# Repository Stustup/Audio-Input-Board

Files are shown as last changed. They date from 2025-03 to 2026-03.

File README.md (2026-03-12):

# Audio Input Board

A simple input board to interface multiple connectors with DIY projects. I use it mainly as connector boards for prototyping tube amps, which are wired point to point. Adding flimsy cables with connectors soldered to them was and would be tedious. 
Also this makes it possible to securely attach oscilloscope probes on the test holes.

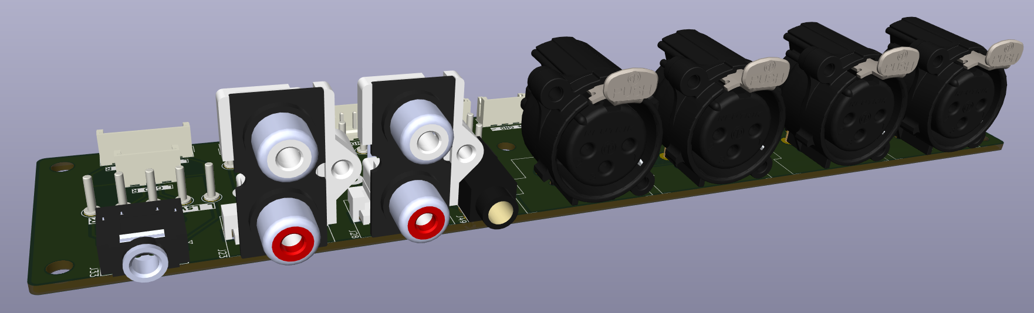
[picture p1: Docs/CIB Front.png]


## Connectors on the board are:
1. 3.5mm Stereo Jack
2. 2 Stereo Chinch/RCA connectors (for input/output)
3. 4.4mm Differential Pentaconn connector, because i like it and want to push it.
3. 4 Mono Differential XLR connectors (for input/output). One could use each of these as a single stereo Jack 

To interface these connectors to your DIY project you need a few JST_EH P2.50mm connectors and cables, which are the (it looks like to me) standard for cheap knock off DIY connectors in sets on eBay. 

You could also just solder wires to the holes corresponding to the input jack.

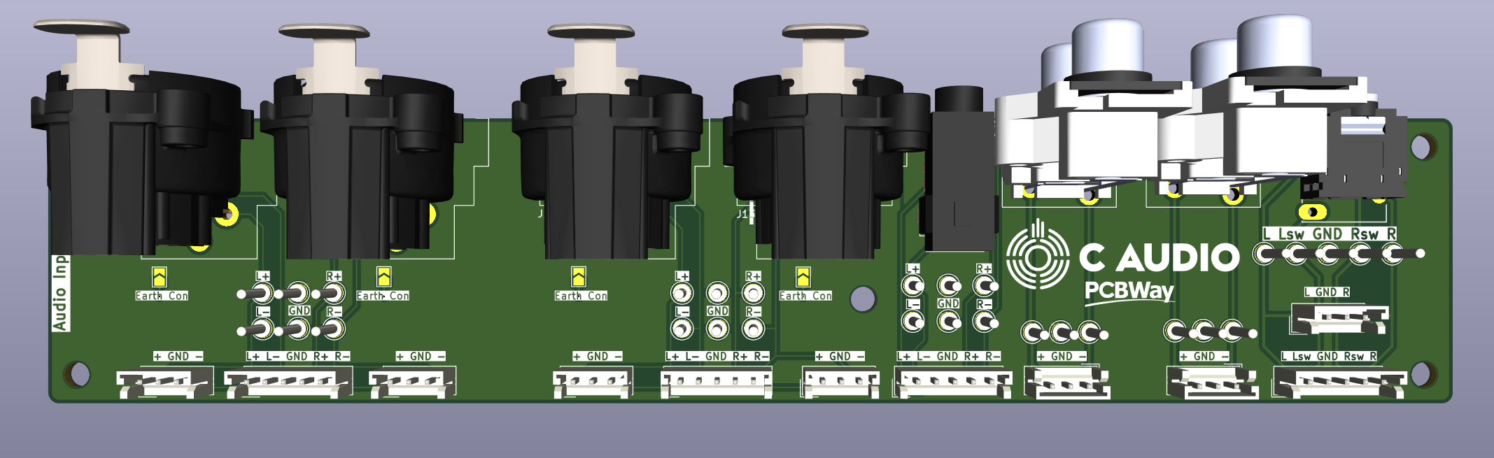
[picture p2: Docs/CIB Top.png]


The XLR connectors wre wired somewhat weirdly, like you can see in the next picture:

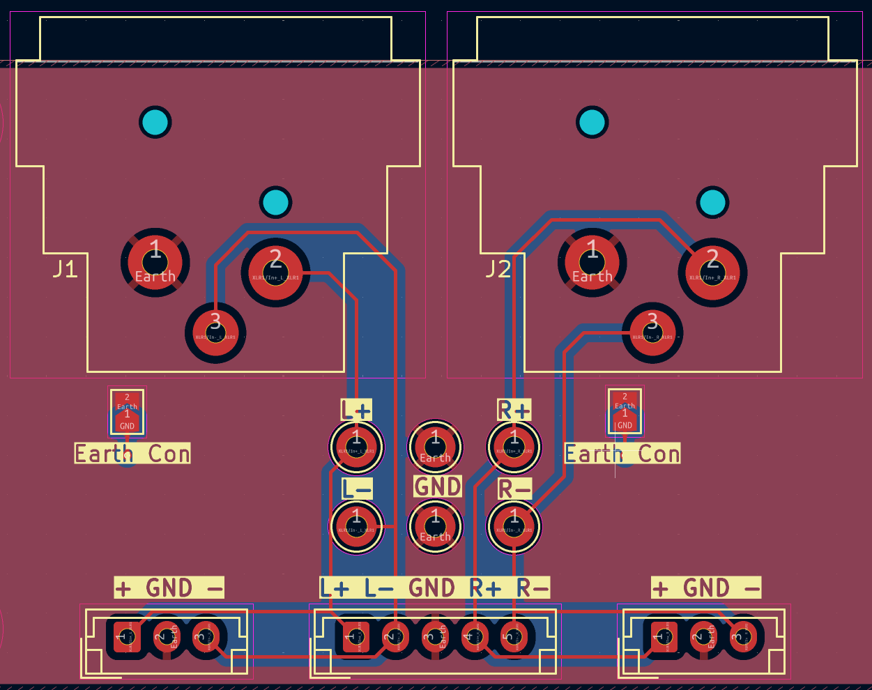
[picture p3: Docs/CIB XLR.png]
XLR connections


As you can see, the top pins are the hot pins and the bottom pins are the cold pins. Use this as you like. The pin 1 of the XLR (used for ground or Earth) is connected only to the GND plane on the XLR side. To connect this to the GND of the single ended Jacks (RCA and 3.5mm) and the pentaconn one you have to solder the little "Earth_Con" jumper. 

The switched contacts of the 3.5mm jack are broken out, too.

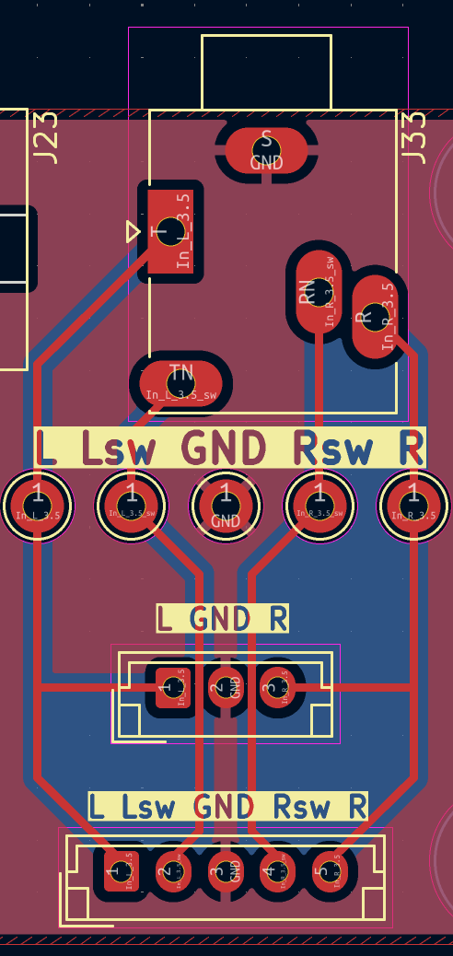
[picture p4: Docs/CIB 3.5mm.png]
Stereo Jack wiring


## Notes

The 3D models of the connectors are not in this repository, you can grab these on GrabCAD.

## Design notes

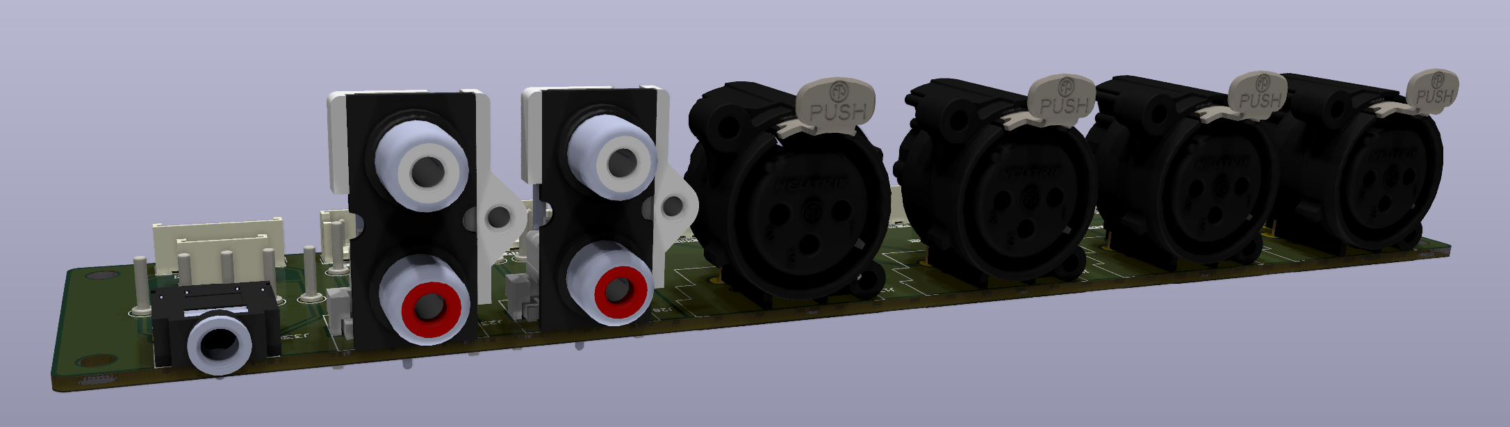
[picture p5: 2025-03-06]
Docs/3d-model-front.png

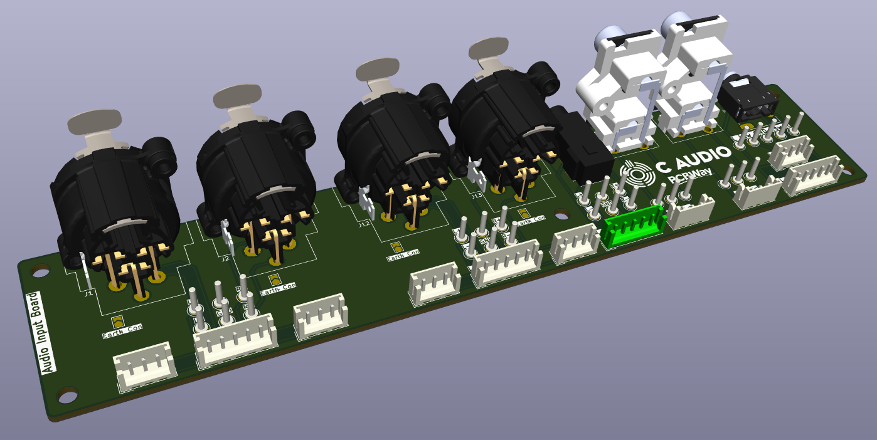
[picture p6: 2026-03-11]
Docs/CIB Back side.png

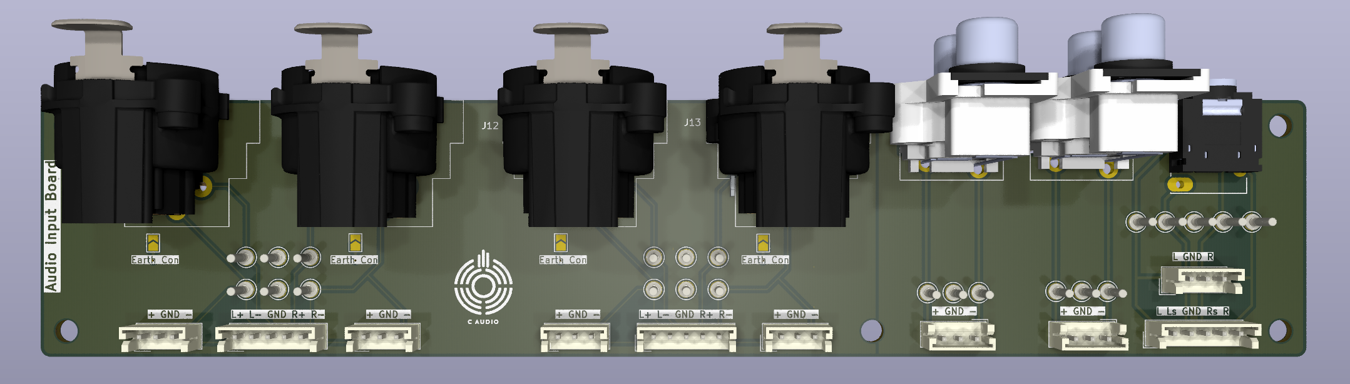
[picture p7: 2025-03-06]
Docs/3d-model-top.png

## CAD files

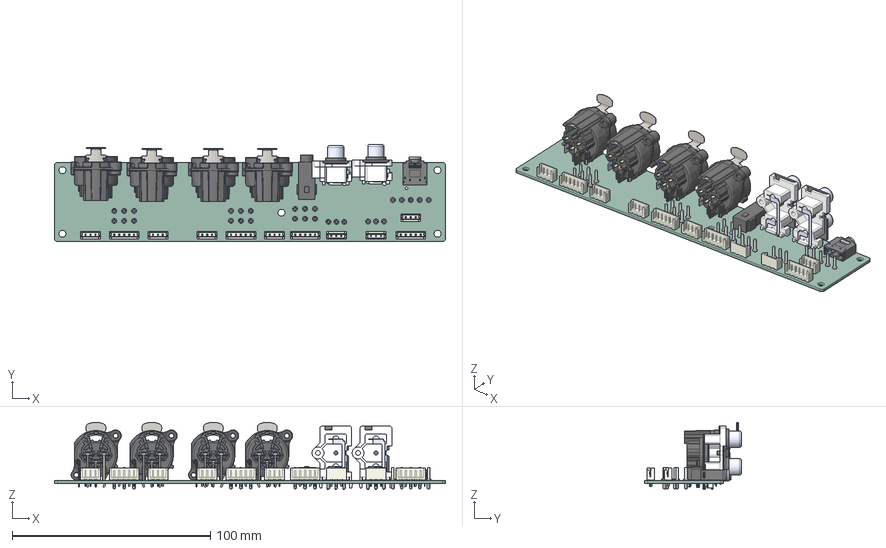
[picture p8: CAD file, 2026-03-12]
CAD/C-Audio Input Board 3D Model.step
197.0 x 49.0 x 33.9 mm
JST_EH_B3B-EH-A_1x03_P2.50mm_Vertical x 7
JST_EH_B5B-EH-A_1x05_P2.50mm_Vertical x 4
Neutrik NC3FAH2 x 4
Pin_D1.3mm_L11.0mm x 29
pentaconn
RS-209 x 2
ST-212
C-Audio Input Board_PCB

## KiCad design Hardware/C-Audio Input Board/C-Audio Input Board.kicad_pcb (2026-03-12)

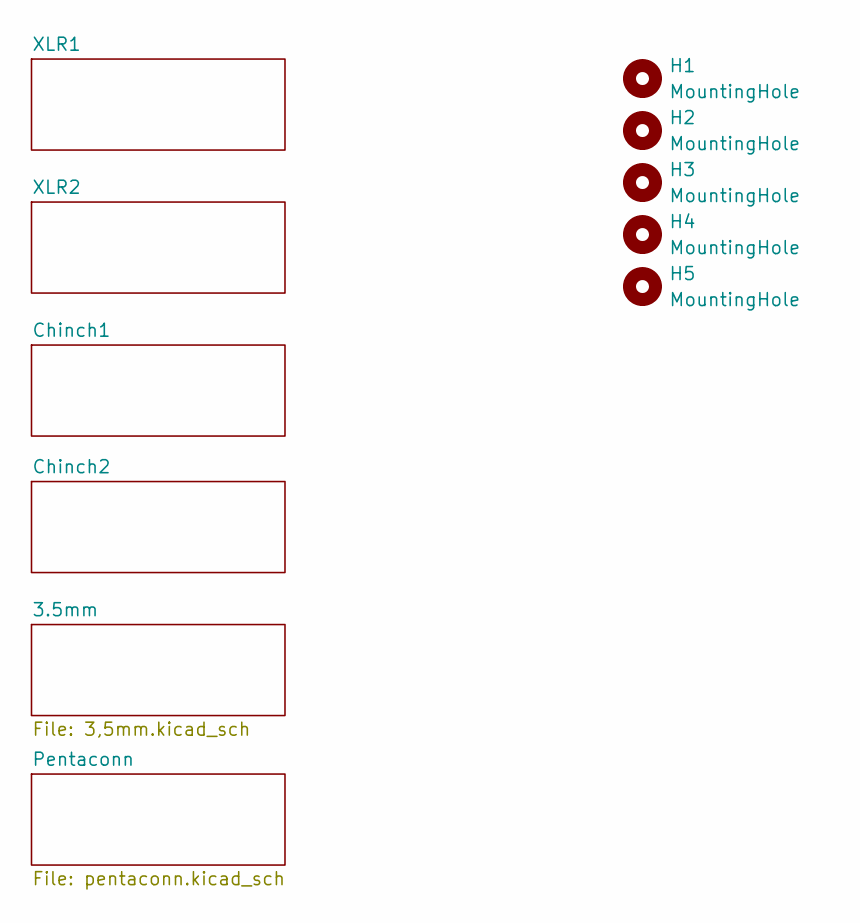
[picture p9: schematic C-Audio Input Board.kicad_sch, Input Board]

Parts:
H1, H2, H3, H4, H5: MountingHole; MountingHole_3.5mm

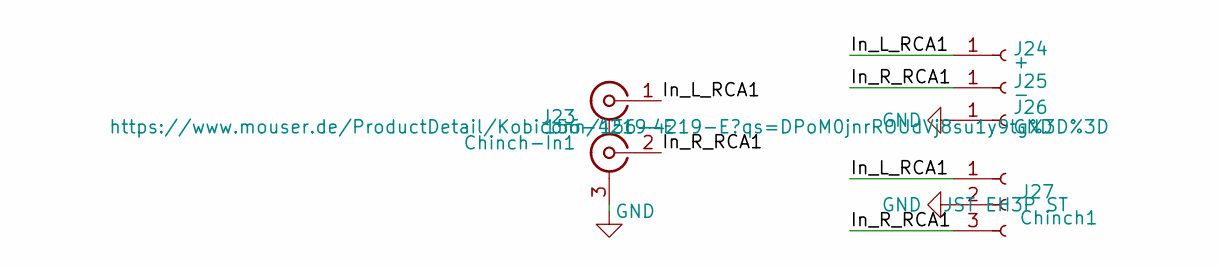
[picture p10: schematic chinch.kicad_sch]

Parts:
J23: Chinch-In1; CBP 2; Mouser Nr. 156-4219-E
J24: +; Pin_D1.3mm_L11.0mm
J25: -; Pin_D1.3mm_L11.0mm
J26: GND; Pin_D1.3mm_L11.0mm
J27: Chinch1; JST_EH_B3B-EH-A_1x03_P2.50mm_Vertical

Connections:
/Chinch1/In_L_RCA1: J23.1 (IN1), J24.1, J27.1
/Chinch1/In_R_RCA1: J23.2 (IN2), J25.1, J27.3
GND: J23.3 (EXT), J26.1, J27.2; also elsewhere on the board

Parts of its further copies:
J28: Chinch-In1; CBP 2; Mouser Nr. 156-4219-E
J29: +; Pin_D1.3mm_L11.0mm
J30: -; Pin_D1.3mm_L11.0mm
J31: GND; Pin_D1.3mm_L11.0mm
J32: Chinch1; JST_EH_B3B-EH-A_1x03_P2.50mm_Vertical

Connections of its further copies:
/Chinch2/In_L_RCA1: J28.1 (IN1), J29.1, J32.1
/Chinch2/In_R_RCA1: J28.2 (IN2), J30.1, J32.3
GND: J28.3 (EXT), J31.1, J32.2; also elsewhere on the board

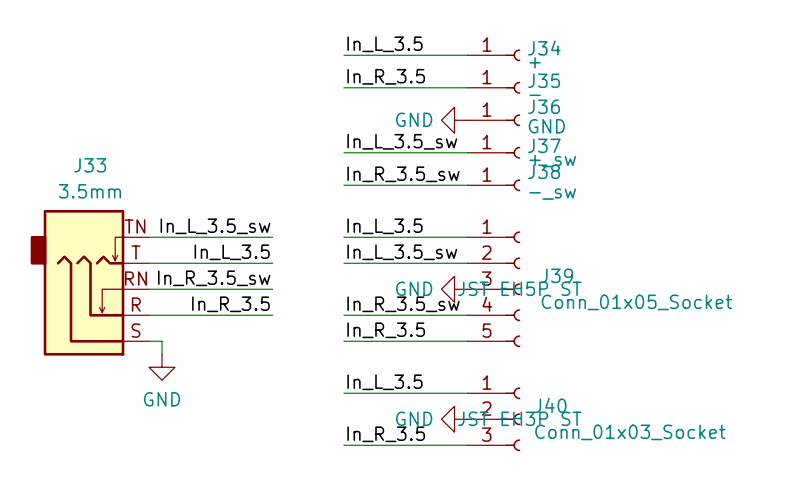
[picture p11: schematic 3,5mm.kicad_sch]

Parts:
J33: 3.5mm; Jack_3.5mm_Ledino_KB3SPRS_Horizontal
J34: +; Pin_D1.3mm_L11.0mm
J35: -; Pin_D1.3mm_L11.0mm
J36: GND; Pin_D1.3mm_L11.0mm
J37: +_sw; Pin_D1.3mm_L11.0mm
J38: -_sw; Pin_D1.3mm_L11.0mm
J39: Conn_01x05_Socket; JST_EH_B5B-EH-A_1x05_P2.50mm_Vertical
J40: Conn_01x03_Socket; JST_EH_B3B-EH-A_1x03_P2.50mm_Vertical

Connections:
/3.5mm/In_L_3.5: J33.T, J34.1, J39.1, J40.1
/3.5mm/In_L_3.5_sw: J33.TN, J37.1, J39.2
/3.5mm/In_R_3.5: J33.R, J35.1, J39.5, J40.3
/3.5mm/In_R_3.5_sw: J33.RN, J38.1, J39.4
GND: J33.S, J36.1, J39.3, J40.2; also elsewhere on the board

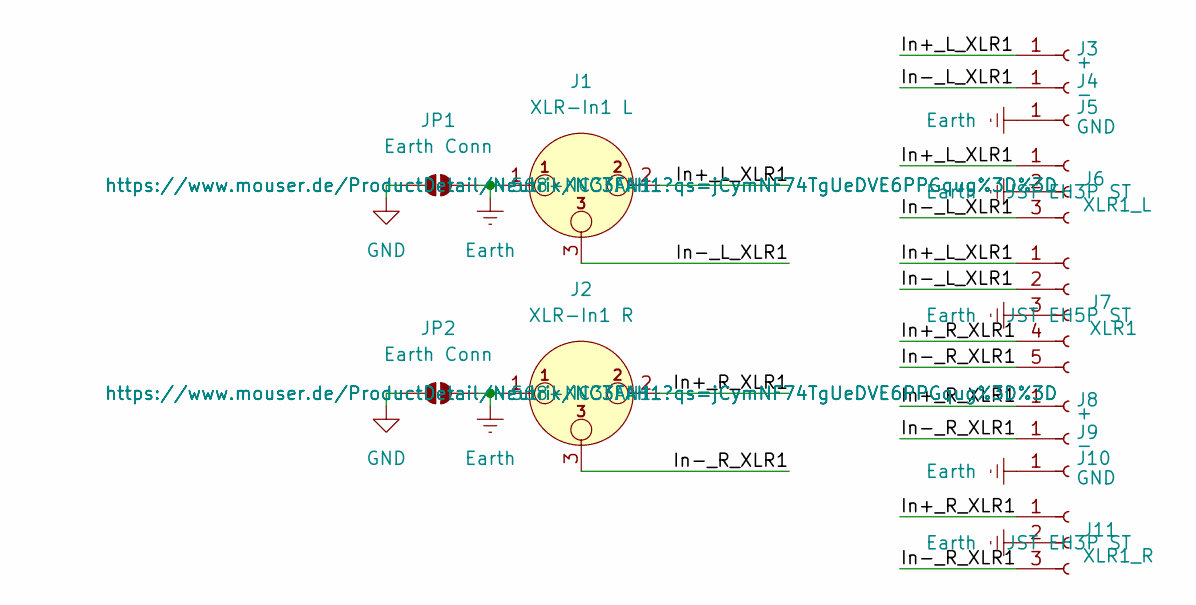
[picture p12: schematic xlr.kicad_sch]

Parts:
J1: XLR-In1 L; Jack_XLR_Neutrik_NC3FAH1_Horizontal; Mouser Nr. 568-NC3FAH1
J2: XLR-In1 R; Jack_XLR_Neutrik_NC3FAH1_Horizontal; Mouser Nr. 568-NC3FAH1
J3, J8: +; Pin_D1.3mm_L11.0mm
J4, J9: -; Pin_D1.3mm_L11.0mm
J5, J10: GND; Pin_D1.3mm_L11.0mm
J6: XLR1_L; JST_EH_B3B-EH-A_1x03_P2.50mm_Vertical
J7: XLR1; JST_EH_B5B-EH-A_1x05_P2.50mm_Vertical
J11: XLR1_R; JST_EH_B3B-EH-A_1x03_P2.50mm_Vertical
JP1, JP2: Earth Conn; SolderJumper-2_P1.3mm_Open_TrianglePad1.0x1.5mm

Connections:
/XLR1/In+_L_XLR1: J1.2, J3.1, J6.1, J7.1
/XLR1/In+_R_XLR1: J2.2, J7.4, J8.1, J11.1
/XLR1/In-_L_XLR1: J1.3, J4.1, J6.3, J7.2
/XLR1/In-_R_XLR1: J2.3, J7.5, J9.1, J11.3
Earth: J1.1, J2.1, J5.1, J6.2, J7.3, J10.1, J11.2, JP1.2 (B), JP2.2 (B); also elsewhere on the board
GND: JP1.1 (A), JP2.1 (A); also elsewhere on the board

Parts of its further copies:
J12: XLR-In1 L; Jack_XLR_Neutrik_NC3FAH1_Horizontal; Mouser Nr. 568-NC3FAH1
J13: XLR-In1 R; Jack_XLR_Neutrik_NC3FAH1_Horizontal; Mouser Nr. 568-NC3FAH1
J14, J19: +; Pin_D1.3mm_L11.0mm
J15, J20: -; Pin_D1.3mm_L11.0mm
J16, J21: GND; Pin_D1.3mm_L11.0mm
J17: XLR1_L; JST_EH_B3B-EH-A_1x03_P2.50mm_Vertical
J18: XLR1; JST_EH_B5B-EH-A_1x05_P2.50mm_Vertical
J22: XLR1_R; JST_EH_B3B-EH-A_1x03_P2.50mm_Vertical

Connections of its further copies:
/XLR2/In+_L_XLR1: J12.2, J14.1, J17.1, J18.1
/XLR2/In+_R_XLR1: J13.2, J18.4, J19.1, J22.1
/XLR2/In-_L_XLR1: J12.3, J15.1, J17.3, J18.2
/XLR2/In-_R_XLR1: J13.3, J18.5, J20.1, J22.3
Earth: J12.1, J13.1, J16.1, J17.2, J18.3, J21.1, J22.2; also elsewhere on the board

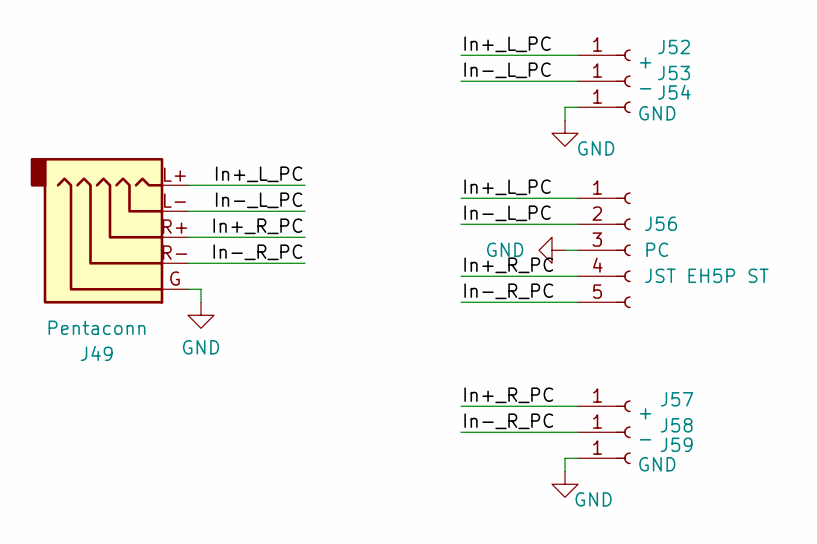
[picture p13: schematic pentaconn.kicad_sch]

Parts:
J49: Pentaconn
J52, J57: +; Pin_D1.3mm_L11.0mm
J53, J58: -; Pin_D1.3mm_L11.0mm
J54, J59: GND; Pin_D1.3mm_L11.0mm
J56: PC; JST_EH_B5B-EH-A_1x05_P2.50mm_Vertical

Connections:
/Pentaconn/In+_L_PC: J49.L+, J52.1, J56.1
/Pentaconn/In+_R_PC: J49.R+, J56.4, J57.1
/Pentaconn/In-_L_PC: J49.L-, J53.1, J56.2
/Pentaconn/In-_R_PC: J49.R-, J56.5, J58.1
GND: J49.G, J54.1, J56.3, J59.1; also elsewhere on the board

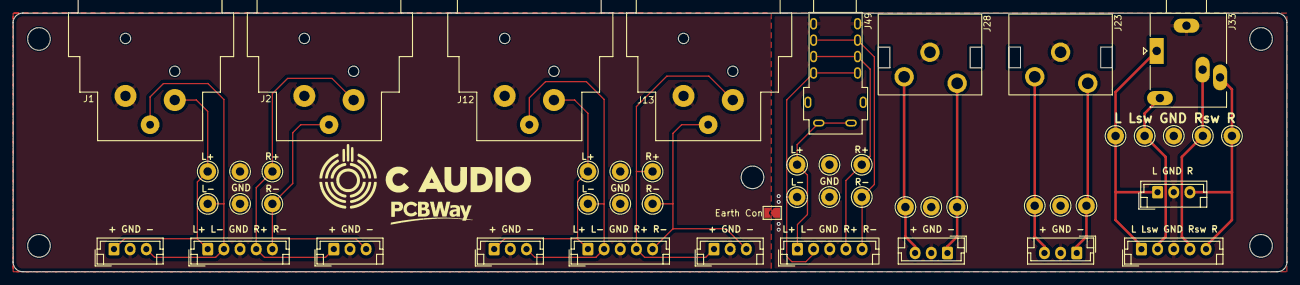
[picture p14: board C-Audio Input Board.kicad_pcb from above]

Board: 2 copper layers, 197.0 x 40.0 mm, 54 parts (0 on the bottom side), 22 nets.

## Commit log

2025-03-10 added mouser and reichelt numbers to BOM
    [3,5mm.kicad_sch, C-Audio Input Board.kicad_sch, chinch.kicad_sch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]
2025-03-10 added BOM
    [C-Audio Input Board.csv, C-Audio Input Board.kicad_pcb]
2025-03-10 bom directory
    [C-Audio Input Board BOM.csv]
2026-03-11 added pentaconn and silkscreen marking. Also added PCBWay logo for sponsorship
    [C-Audio Input Board.kicad_pcb, C-Audio Input Board.kicad_sch, chinch.kicad_sch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]
2026-03-11 added BOM and new gerbers
    [C-Audio Input Board BOM.csv, C-Audio Input Board.kicad_pcb]
2026-03-11 updated README and 3D Models
    [C-Audio Input Board-B_Cu.gbr, C-Audio Input Board-B_Mask.gbr, C-Audio Input Board-B_Paste.gbr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]
2026-03-11 added new 3D model#
    [C-Audio Input Board 3D Model.step]
2026-03-12 finalized Silkscreen and production data
    [C-Audio Input Board 3D Model.step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]
